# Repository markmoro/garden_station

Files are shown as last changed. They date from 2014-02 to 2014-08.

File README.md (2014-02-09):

Garden Station
==============

Single board garden watering controller based on Arduino.

This is a single board AT-MEGA controller.   This has an interface for a display, some LED indicators, inputs for moisture sensors and outputs for servo controller valves.   

Code is now added and the board has now been replaced with an SMD version.  The original prototype board is in the old folder, however there are some wiring issues with the shift registers which require some jumper wire.   This can be seen on the blog page photo.

More details are available on [http://makicity.com/](http://makicity.com/)

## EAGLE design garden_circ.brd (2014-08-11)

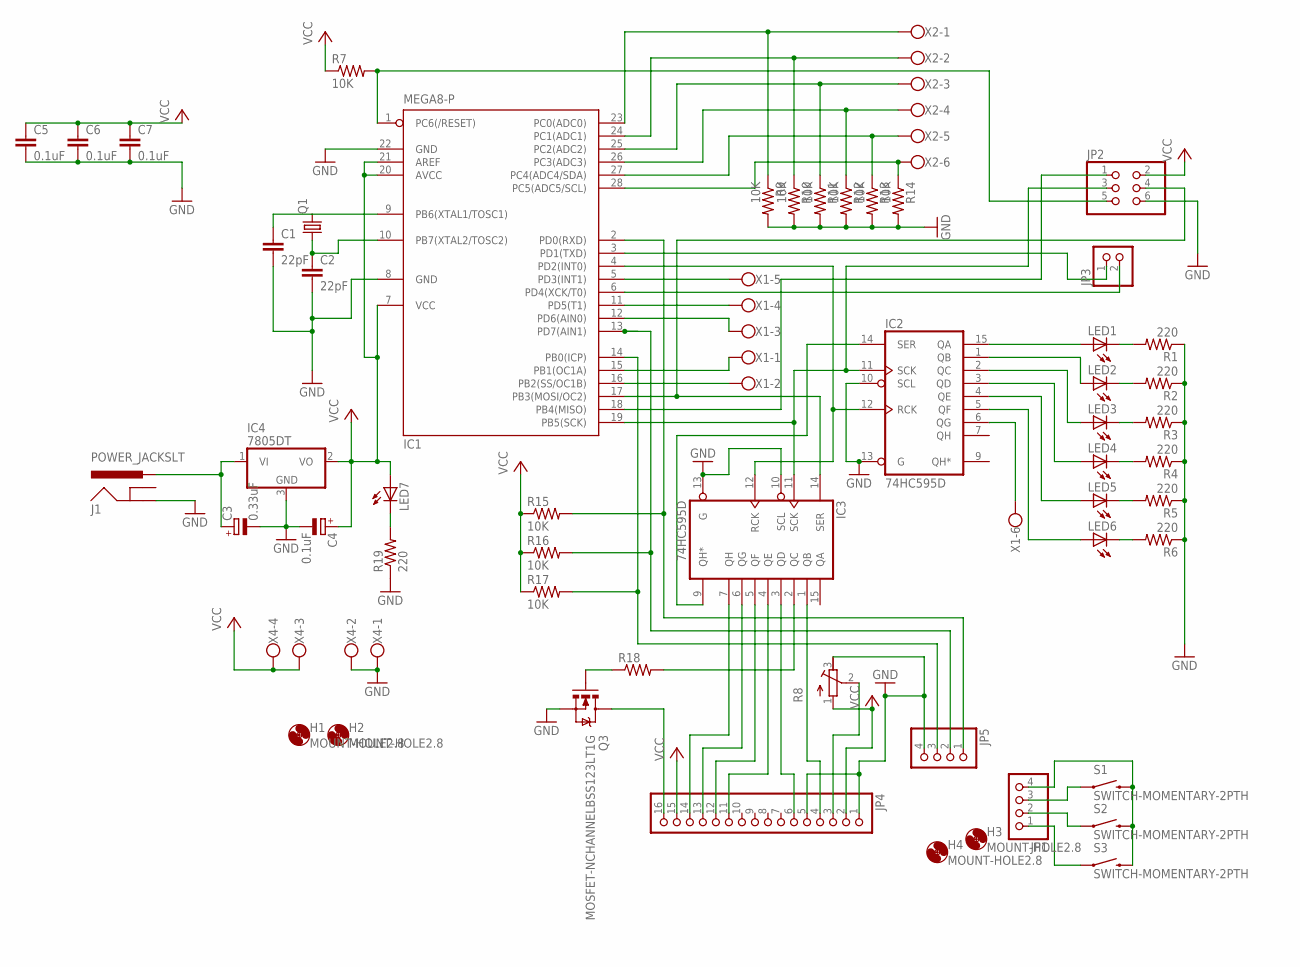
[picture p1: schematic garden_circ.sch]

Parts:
C1, C2: 22pF; 0805
C3: 0.33uF; SMC_C
C4: 0.1uF; SMC_C
C5, C6, C7: 0.1uF; 0805
H1, H2, H3, H4: MOUNT-HOLE2.8; 2,8
IC1: MEGA8-P; DIL28-3
IC2, IC3: 74HC595D; SO16
IC4: 7805DT; TO252
J1: POWER_JACKSLT; POWER_JACK_SLOT
JP1, JP5: PINHD-1X4; 1X04
JP2: PINHD-2X3; 2X03
JP3: PINHD-1X2; 1X02
JP4: PINHD-1X16; 1X16
LED1, LED2, LED3, LED4, LED5, LED6: LED3MM
LED7: LEDSML0805; SML0805
Q1: CRYSTALHC49UP; HC49UP
Q3: MOSFET-NCHANNELBSS123LT1G; SOT23
R1, R2, R3, R4, R5, R6, R19: 220; 0805
R7, R9, R10, R11, R12, R13, R14, R15, R16, R17: 10K; 0805
R8: R-TRIMM3202; RTRIM3202
R18: RESISTOR0805-RES; 0805
S1, S2, S3: SWITCH-MOMENTARY-2PTH; TACTILE-PTH
X1, X2: W237-136
X4: W237-4

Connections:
GND: C1.2, C2.2, C3.-, C4.-, C5.2, C6.2, C7.2, IC1.8 (GND), IC1.22 (GND), IC2.8 (GND), IC2.10 (SCL), IC2.13 (G), IC3.8 (GND), IC3.10 (SCL), IC3.13 (G), IC4.3 (GND), J1.GND@2 (GND), JP2.6, JP4.1, JP4.5, JP5.4, Q3.2 (S), R1.1, R2.1, R3.1, R4.1, R5.1, R6.1, R8.3 (A), R9.2, R10.2, R11.2, R12.2, R13.2, R14.2, R19.1, X4.1, X4.2
MISO: IC1.18 (PB4(MISO)), JP2.1
unnamed: C1.1, IC1.9 (PB6(XTAL1/TOSC1)), Q1.2
unnamed: C2.1, IC1.10 (PB7(XTAL2/TOSC2)), Q1.1
unnamed: LED1.K (C), R1.2
unnamed: LED2.K (C), R2.2
unnamed: LED3.K (C), R3.2
unnamed: LED4.K (C), R4.2
unnamed: LED5.K (C), R5.2
unnamed: LED6.K (C), R6.2
unnamed: IC2.6 (QG), X1.6
unnamed: IC1.1 (PC6(/RESET)), JP2.5, R7.2
unnamed: IC2.15 (QA), LED1.A
unnamed: IC2.1 (QB), LED2.A
unnamed: IC2.2 (QC), LED3.A
unnamed: IC2.3 (QD), LED4.A
unnamed: IC1.11 (PD5(T1)), X1.4
unnamed: IC2.4 (QE), LED5.A
unnamed: IC2.5 (QF), LED6.A
unnamed: IC1.6 (PD4(XCK/T0)), JP3.2
unnamed: IC1.19 (PB5(SCK)), IC2.11 (SCK), IC3.11 (SCK), JP2.3
unnamed: IC2.14 (SER), IC3.9 (QH*)
unnamed: IC1.12 (PD6(AIN0)), X1.3
unnamed: IC1.15 (PB1(OC1A)), X1.1
unnamed: IC1.24 (PC1(ADC1)), R10.1, X2.2
unnamed: IC3.3 (QD), JP4.6
unnamed: IC3.1 (QB), JP4.4
unnamed: IC3.7 (QH), JP4.14
unnamed: IC3.6 (QG), JP4.13
unnamed: IC3.5 (QF), JP4.12
unnamed: IC1.23 (PC0(ADC0)), R9.1, X2.1
unnamed: IC1.25 (PC2(ADC2)), R11.1, X2.3
unnamed: IC1.26 (PC3(ADC3)), R12.1, X2.4
unnamed: IC1.27 (PC4(ADC4/SDA)), R13.1, X2.5
unnamed: IC1.28 (PC5(ADC5/SCL)), R14.1, X2.6
unnamed: IC1.16 (PB2(SS/OC1B)), X1.2
unnamed: C3.+, IC4.1 (VI), J1.PWR
unnamed: IC1.2 (PD0(RXD)), JP5.1, R15.2
unnamed: IC1.13 (PD7(AIN1)), JP5.2, R16.2
unnamed: IC1.14 (PB0(ICP)), JP5.3, R17.2
unnamed: IC1.5 (PD3(INT1)), X1.5
unnamed: IC1.17 (PB3(MOSI/OC2)), IC3.14 (SER), JP2.4
unnamed: IC1.3 (PD1(TXD)), JP3.1
unnamed: IC1.4 (PD2(INT0)), IC2.12 (RCK), IC3.12 (RCK)
unnamed: JP4.3, R8.2 (S)
unnamed: IC3.4 (QE), JP4.11
unnamed: JP1.1, S3.1
unnamed: JP4.16, Q3.3 (D)
unnamed: Q3.1 (G), R18.1
unnamed: IC3.2 (QC), R18.2
unnamed: JP1.2, S2.1
unnamed: JP1.3, S1.1
unnamed: JP1.4, S1.3 (2), S2.3 (2), S3.3 (2)
unnamed: LED7.C, R19.2
VCC: C4.+, C5.1, C6.1, C7.1, IC1.7 (VCC), IC1.20 (AVCC), IC1.21 (AREF), IC2.16 (VCC), IC3.16 (VCC), IC4.2 (VO), JP2.2, JP4.2, JP4.15, LED7.A, R7.1, R8.1 (E), R15.1, R16.1, R17.1, X4.3, X4.4

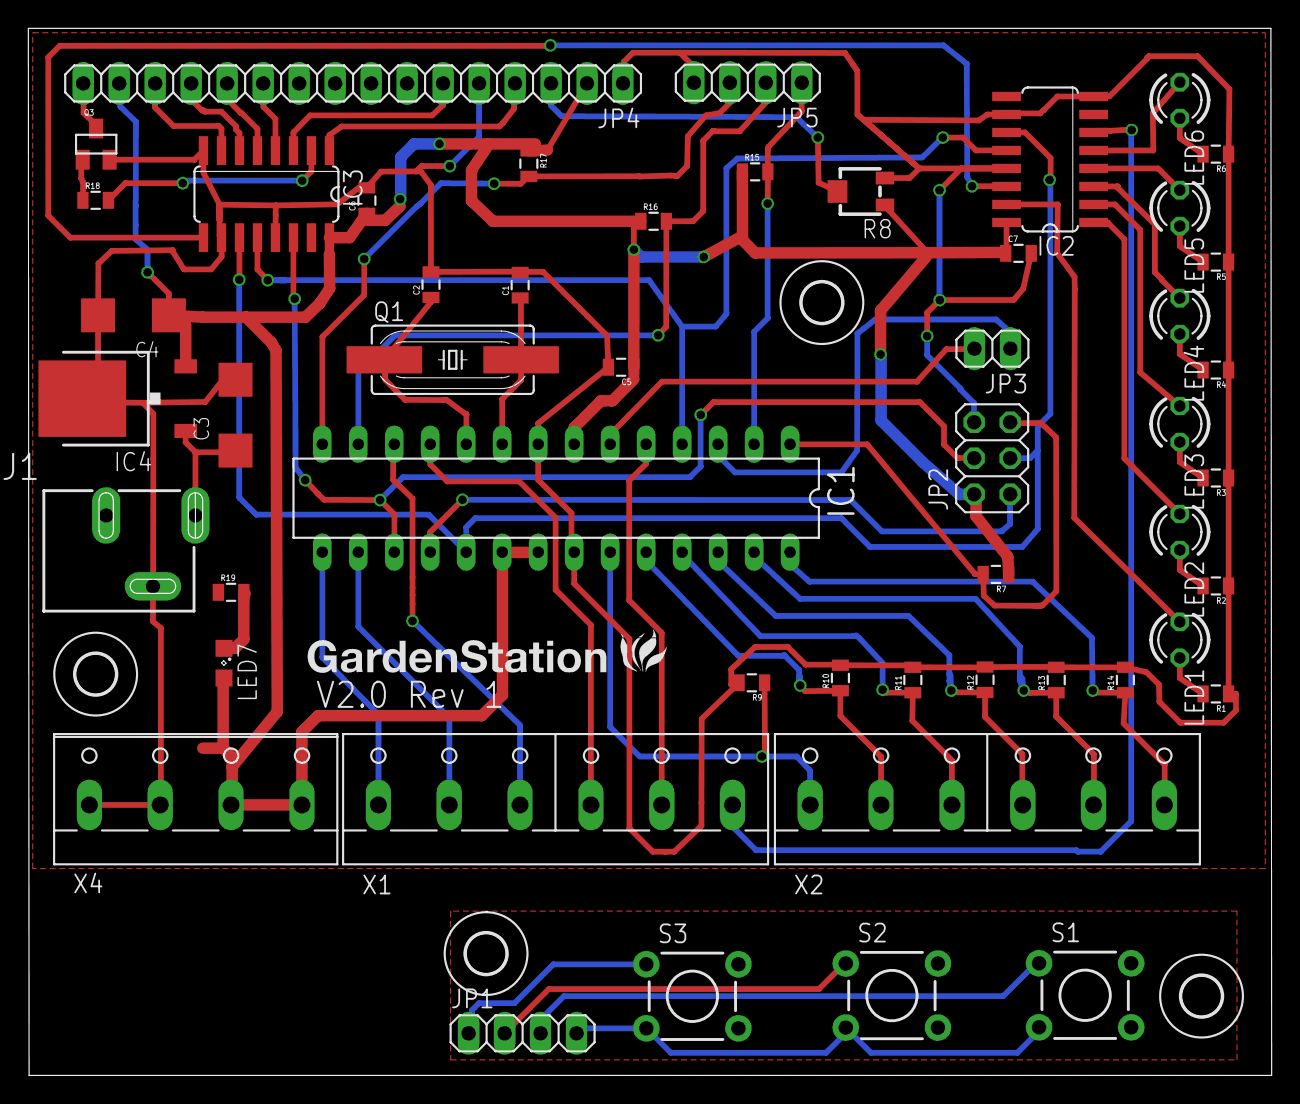
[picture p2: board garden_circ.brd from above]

Board: 2 copper layers, 87.8 x 73.9 mm, 55 parts (0 on the bottom side), 55 nets.

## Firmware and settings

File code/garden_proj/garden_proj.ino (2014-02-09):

#include <SPI.h>
#include <LiquidCrystal2.h>
#include <Servo.h> 

const int DATA_PIN = 11;
const int LATCH_PIN =13;
const int CLOCK_PIN = 2;

const int VALVE_OPEN = 0;
const int VALVE_CLOSED = 180;
const int WATER_DIV = 10;
const int WATER_FLOW_TIME = 2;
const int WATER_COOL_TIME = -2;

const int SENSOR_OFF = 1024;

const int buttonPins[] = {8,7,0};
const int servoPins[] = {9,10,6,5,3};

int buttonState[3];         // current state of the button
int lastButtonState[3];   

int sensor_number = 0;
int editing = 99;

int thresholds[6];
int pins =0;
int alerts[6];

int water_divider;

int servoTime[5];

int setupScreen;
int setupServo;

int  uiMode;
Servo servo;


LiquidCrystal2 lcd(CLOCK_PIN);
 
void setup() {
  
  uiMode =0;
  pinMode(DATA_PIN, OUTPUT);
  pinMode(LATCH_PIN, OUTPUT);
  pinMode(CLOCK_PIN, OUTPUT);
  pinMode(buttonPins[0], INPUT);   
  pinMode(buttonPins[1], INPUT);   
  pinMode(buttonPins[2], INPUT); 

  //  Setup servos to off position
  for(int i=0;i<5;i++) {
    servoTime[i]=0; 
    servo.attach(servoPins[i]);
    servo.write(VALVE_CLOSED); 
    servo.detach();
  }
  
  //  Clear button states
  for(int i=0;i<3;i++) {
    buttonState[i]=digitalRead(i);
    lastButtonState[i]=buttonState[i]; 
  }
  
  //  Setup water divider
  water_divider = WATER_DIV;

  // Tresholds
  thresholds[0] = 500;
  thresholds[1] = SENSOR_OFF;
  thresholds[2] = SENSOR_OFF;
  thresholds[3] = SENSOR_OFF;
  thresholds[4] = SENSOR_OFF;
  setupScreen = 0;
  
  setupServo 
  //Serial.begin(9600);   
  lcd.begin(20, 2);
  lcd.print("Sensor 0");
}
 
boolean checkButtonPress(int button_no) {
  boolean ret = false;
  buttonState[button_no] = digitalRead(buttonPins[button_no]);
  // compare the buttonState to its previous state
  if (buttonState[button_no] != lastButtonState[button_no]) {
    // if the state has changed, increment the counter
    if (buttonState[button_no] == HIGH) {
      // if the current state is HIGH then the button
      // wend from off to on:
      ret = true;
     } 
  }
  lastButtonState[button_no] = buttonState[button_no];
  return ret;
}

void setupLoop() {
  if( checkButtonPress(2) && setupScreen == 0) {
      uiMode = 0;
      return; 
  }
  if( checkButtonPress(1)) {
    setupServo = VALVE_CLOSED;
    for(int i=0;i<5;i++) { 
      servo.attach(servoPins[i]);
      servo.write(VALVE_CLOSED); 
      delay(400);
      servo.detach();
    }
  }
  if( checkButtonPress(2)) {
    setupServo = VALVE_OPEN;
    for(int i=0;i<5;i++) { 
      servo.attach(servoPins[i]);
      servo.write(VALVE_OPEN);
      delay(400); 
      servo.detach();
    }
  }
  lcd.setCursor(0, 0);
  lcd.print("Valve Setup ");

  lcd.setCursor(0, 1);
  if(setupServo = VALVE_OPEN) {
    lcd.print("Open   ");  
  } else {
    lcd.print("Close   "); 
  }
 
}



void editLoop() {
   if( checkButtonPress(2) ) {
      uiMode = 0;
      return; 
  }
  
  if( checkButtonPress(0) && thresholds[sensor_number] > 0) {
      thresholds[sensor_number]=thresholds[sensor_number]-100;
  }
  
   if( checkButtonPress(1) && thresholds[sensor_number] < SENSOR_OFF) {
      thresholds[sensor_number]=thresholds[sensor_number]+100;
      if(thresholds[sensor_number] > SENSOR_OFF)
        thresholds[sensor_number] = SENSOR_OFF;
  }
  
  
  lcd.setCursor(0, 0);
  lcd.print("E Sensor ");
  lcd.print(sensor_number);
  lcd.print(" - ");
  
  if(thresholds[sensor_number] < SENSOR_OFF) {
    lcd.print(thresholds[sensor_number]);
    lcd.print("   ");  
  } else {
    lcd.print("Off   "); 
  }
  
  lcd.setCursor(0, 1);
  lcd.print("Editing...");
}



void normalLoop() {
  if( checkButtonPress(1) ) {
      sensor_number++;
       if(sensor_number > 4)
         sensor_number= 0;
    
  }
    if( checkButtonPress(0) ) {
      if(sensor_number == 0)
         sensor_number= 5;
      sensor_number--;
  }
  if( checkButtonPress(2) ) {
      uiMode = 1;
      return; 
  }
  
  
  lcd.setCursor(0, 0);
  lcd.print("Sensor ");
  lcd.print(sensor_number);
  lcd.print(" - ");
  
  if(thresholds[sensor_number] < SENSOR_OFF) {
    int moisture_val = analogRead(sensor_number);
    lcd.print(moisture_val);
    lcd.print("   ");  
  } else {
    lcd.print("Off   "); 
  }
  
  lcd.setCursor(0, 1);
  lcd.print("Temp - ");
  if(thresholds[5] <1024 && thresholds[5] >30) {
    int moisture_val = analogRead(5);
    lcd.print(moisture_val);
    lcd.print((char)223);
    lcd.print("C  ");  
  } else {
    lcd.print("Off   "); 
  }
}

void servoUpdate() {
  if(water_divider == 0 ) {
    water_divider = WATER_DIV;
    for(int i=0;i<5;i++)  {
      if(servoTime[i] == 1) {
        servo.attach(servoPins[i]);
        servo.write(VALVE_CLOSED);  
        servo.detach(); 
      }
      if(servoTime[i] > 0) {
        servoTime[i]--;
        if(servoTime[i] == 0) {
          servoTime[i] = WATER_COOL_TIME;
        }
      }
      if(servoTime[i] < 0) {
        servoTime[i]++;
      }
    }
  }
  water_divider--;
}

void sensorUpdate() {
  pins = 0;
  for(int i=0;i<5;i++)  {
    int moisture_val = analogRead(i);  
    if(thresholds[i] < SENSOR_OFF && moisture_val < thresholds[i]) {
       alerts[i]++;
    } else {
      alerts[i] = 0;
    }
    if(alerts[i] >10) {
      alerts[i] =0;
    }
    if(alerts[i]>5) {
       pins= pins | 32;
       if(servoTime[i] == 0) {
         servoTime[i] = WATER_FLOW_TIME;
         servo.attach(servoPins[i]);
         servo.write(VALVE_OPEN);  
         servo.detach();
       }
    }
    pins= pins >> 1;
  }
}


void loop() {
  sensorUpdate();
  servoUpdate();
  if(uiMode ==0)
    normalLoop();
  if(uiMode ==1)
    editLoop();

 // Serial.println(pins);
  lcd.setSecondPins(pins);
  delay(100);
}

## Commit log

2013-11-15 Initial Version
    [garden_circ.brd, garden_circ.sch]
2013-12-08 Fixed shift register wiring
    [garden_circ.brd, garden_circ.sch]
2014-02-09 Added code an SMD board
    [garden_circ.brd, garden_circ.sch]
2014-02-18 Added the code to powerdown backlight of LCD
2014-08-11 Added a few tweaks and power light
    [garden_circ.brd, garden_circ.sch]

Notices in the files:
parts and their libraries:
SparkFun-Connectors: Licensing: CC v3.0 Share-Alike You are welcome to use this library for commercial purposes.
